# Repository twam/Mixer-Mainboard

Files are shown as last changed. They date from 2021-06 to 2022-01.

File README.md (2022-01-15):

Mixer-Mainboard
===

This repository is part of the USB audio mixer project described on https://www.twam.info/general/building-a-custom-usb-audio-mixer.

## License

[][cc-by-sa]

This work is licensed under a [Creative Commons Attribution-NonCommercial-ShareAlike 4.0 International License][cc-by-sa].

[][cc-by-sa]

[cc-by-sa]: http://creativecommons.org/licenses/by-nc-sa/4.0/
[cc-by-sa-image]: https://licensebuttons.net/l/by-nc-sa/4.0/88x31.png
[cc-by-sa-shield]: https://img.shields.io/badge/License-CC%20BY--NC--SA%204.0-lightgrey.svg

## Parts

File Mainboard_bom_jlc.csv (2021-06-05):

Comment | Designator | Footprint | LCSC Part #
6p8 | C7,C8,C9 | C_0402_1005Metric | C1576
22u | C12,C18 | C_0603_1608Metric | C59461
1u | C29,C34,C36,C38,C40,C42,C44,C46,C48,C21,C23,C31,C25,C27 | C_0402_1005Metric | C52923
10u | C101,C201,C19,C3 | C_0805_2012Metric | C15850
1u | C102,C202,C13,C14,C15 | C_0603_1608Metric | C15849
10u | C103,C203,C10,C11,C16,C17 | C_0603_1608Metric | C19702
2u2 | C104,C106,C204,C206 | C_0603_1608Metric | C23630
20pF | C501,C502 | C_0402_1005Metric | C1554
4u7 | C503,C505,C515,C4,C5,C6 | C_0603_1608Metric | C19666
100n | C504,C506,C507,C508,C509,C510,C511,C512,C513,C514,C516,C105,C107,C205,C207,C1,C2,C33,C35,C37,C39,C41,C43,C45,C47,C49,C20,C22,C24,C30,C32,C50,C26,C28,C51,C52,C53 | C_0402_1005Metric | C1525
yellow | D4 | LED_0603_1608Metric | C72038
white | D5 | LED_0603_1608Metric | C2290
blue | D6 | LED_0603_1608Metric | C72041
green | D7,D1,D2,D3 | LED_0603_1608Metric | C72043
red | D8,D9,D10,D12,D11 | LED_0603_1608Metric | C2286
2A | F1,F2 | Fuse_0603_1608Metric_Pad1.05x0.95mm_HandSolder | C187605
USB1 | J501,J101,J201 | USB_C_Receptacle_XKB_TYPE-C-31-M-12 | C165948
600R/100M | L1,L501,L101,L201,L6,L2 | L_0805_2012Metric | C1017
2u2 | L3,L4,L5 | L_0805_2012Metric | C216156
2N7002 | Q1 | SOT-23 | C8545
15k | R1,R9 | R_0402_1005Metric | C25756
1k | R7,R14,R18 | R_0402_1005Metric | C11702
68k | R8 | R_0402_1005Metric | C36871
150k | R10 | R_0402_1005Metric | C25755
47k | R11 | R_0402_1005Metric | C25792
100k | R12,R13 | R_0402_1005Metric | C25741
51R | R24 | R_0402_1005Metric | C25125
1k5 | R39 | R_0402_1005Metric | C25867
8k06 1% | R105,R205 | R_0603_1608Metric | C23112
5k1 | R501,R502,R101,R102,R201,R202 | R_0402_1005Metric | C25905
12k | R503 | R_0402_1005Metric | C25752
10k | R504,R505,R506,R507,R104,R204,R21,R25,R26,R27,R28,R30,R31,R32,R3,R4,R5 | R_0402_1005Metric | C25744
2k2 | R508 | R_0402_1005Metric | C25879
4k7 | R601,R602,R611,R612,R621,R622,R16,R20,R22,R23,R29,R33,R34,R35,R36,R37,R38,R2,R43,R19,R40,R41,R42 | R_0402_1005Metric | C25900
RESET | SW1 | SW_SPST_B3U-1000P | C231329
PROGRAM | SW2 | SW_SPST_B3U-1000P | C231329
BTN1 | SW3 | SW_SPST_B3U-1000P | C231329
BTN2 | SW4 | SW_SPST_B3U-1000P | C231329
BTN3 | SW5 | SW_SPST_B3U-1000P | C231329
W25Q128JVS | U2 | SOIC-8_5.23x5.23mm_P1.27mm | C97521
TLV62569DBV | U3,U4,U5 | SOT-23-5 | C141836
CAT24C256 | U6 | SOIC-8_3.9x4.9mm_P1.27mm | C6482
USB3320 | U101,U201 | QFN-32-1EP_5x5mm_P0.5mm_EP3.3x3.3mm | C132156
TPS76318 | U102,U202 | SOT-23-5 | C7099
FT2232HQ | U501 | QFN-64-1EP_9x9mm_P0.5mm_EP4.35x4.35mm | C193662
93LCxxBxxOT | U502 | SOT-23-6 | C190271
SG-5032CAN | X1 | Oscillator_SMD_SeikoEpson_SG8002LB-4Pin_5.0x3.2mm | C37076
12M | Y501 | Crystal_SMD_3225-4Pin_3.2x2.5mm | C9002

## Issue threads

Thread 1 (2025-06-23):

Gateware

DragonHunter274, 2025-06-23:
I want to build a similar mixer, would you mind sharing the gateware you use?
i am especially interested in the usb part

twam, 2025-06-23:
Hey!
Although the mixer is running fine for me, the gateware is currently not in a buildable state due to the many changes in nmigen/Amaranth in the last months/years. Therefore I'm a little hesitant to put it online.

The USB part is mainly based on https://github.com/greatscottgadgets/luna. If you have experience with that or maybe have it already running I can dig out the USB descriptors and the USB device I used.

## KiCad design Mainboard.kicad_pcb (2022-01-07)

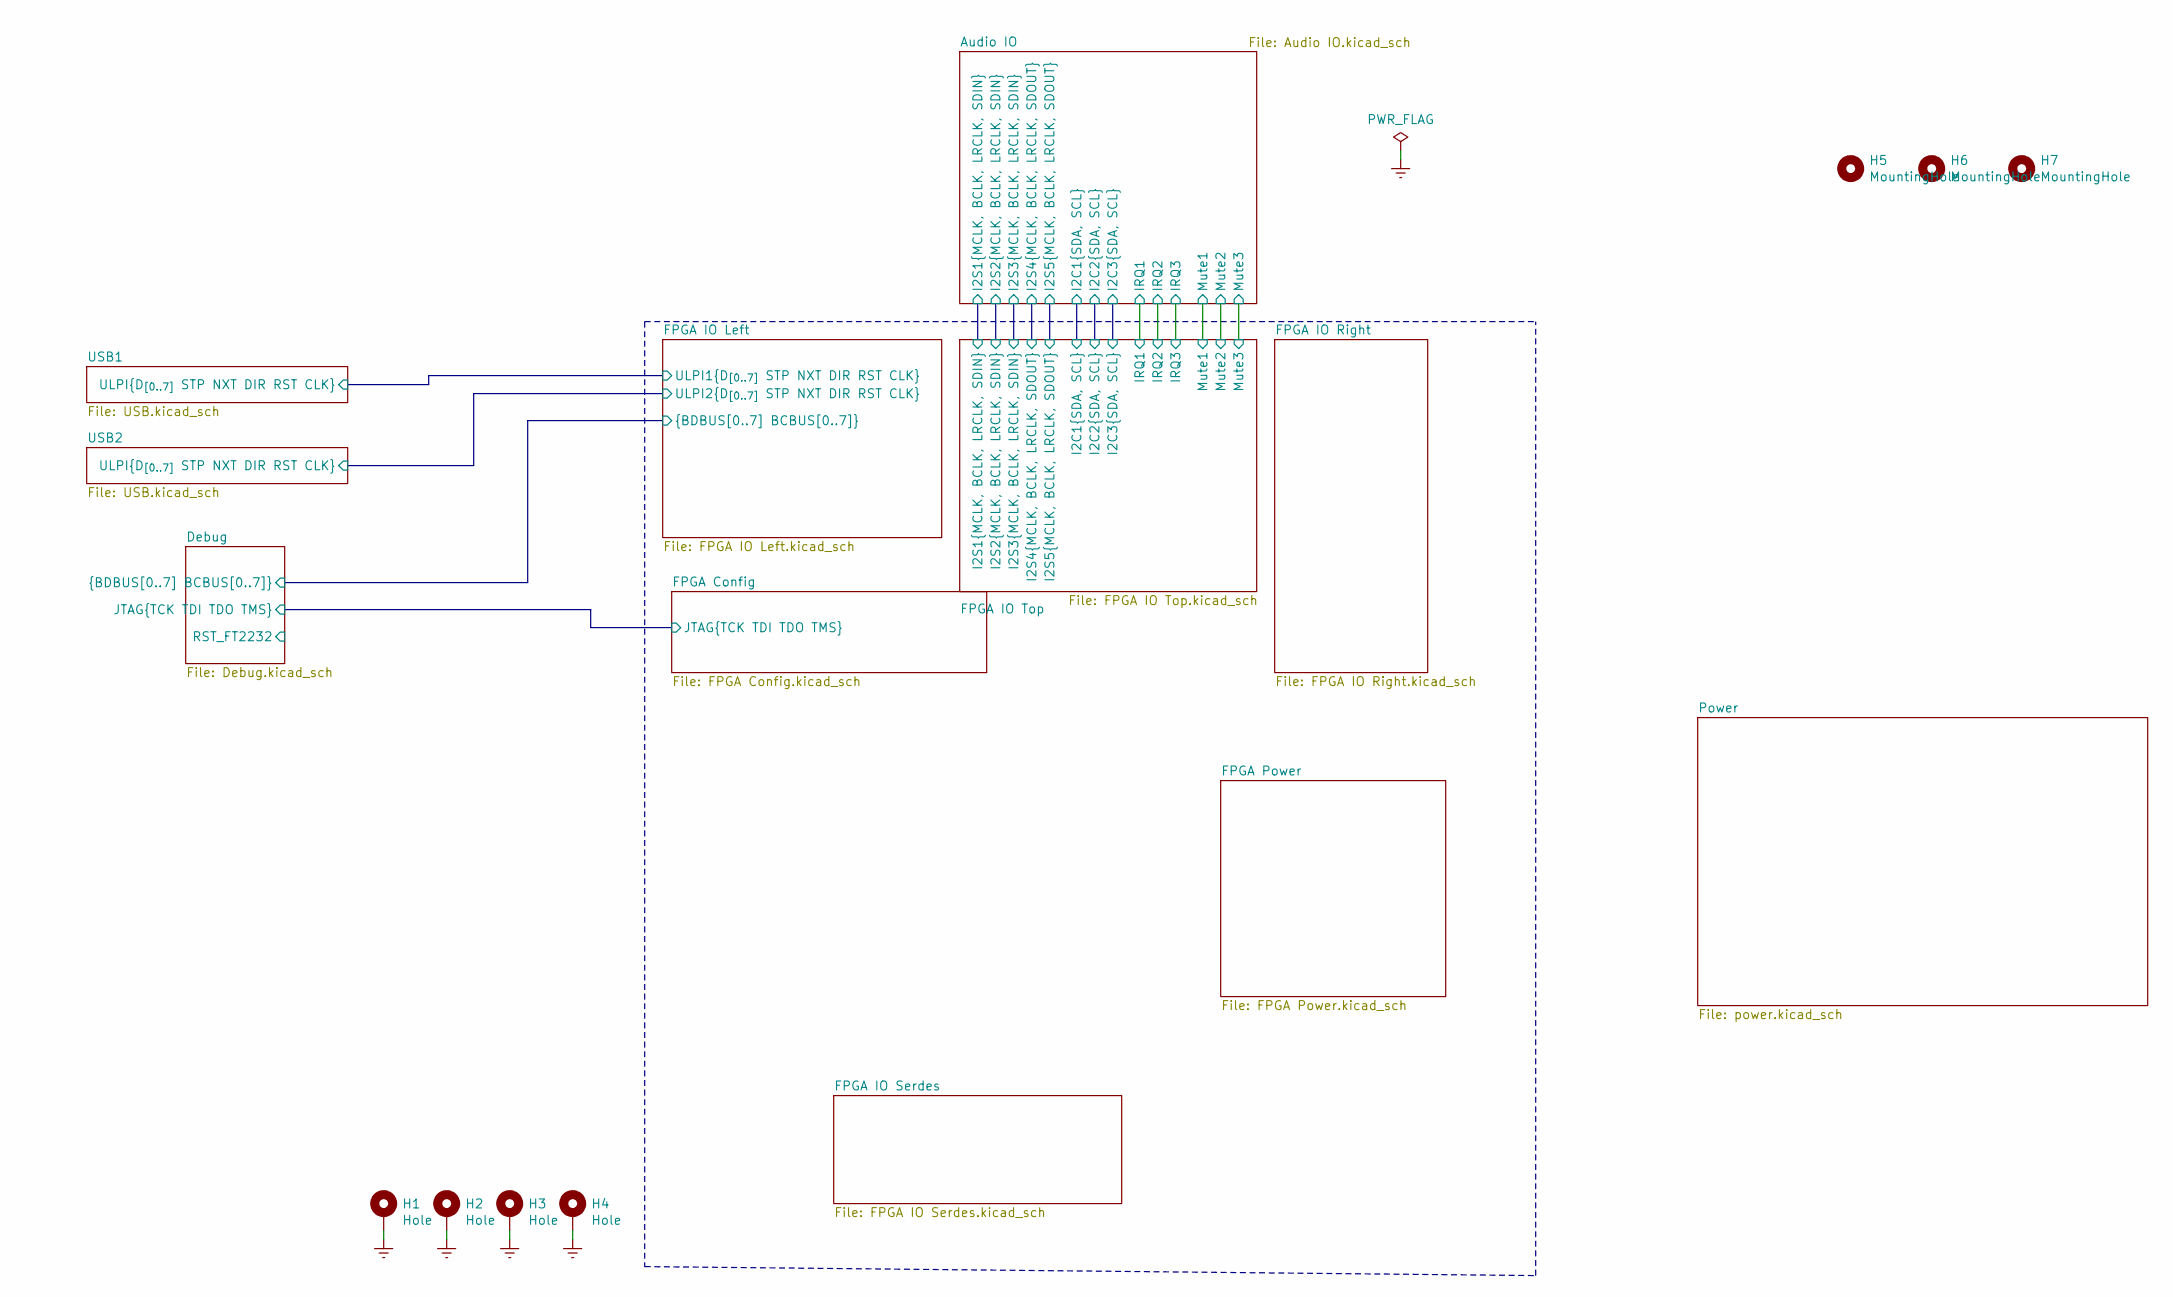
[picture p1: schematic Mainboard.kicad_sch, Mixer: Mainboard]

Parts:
H1, H2, H3, H4: Hole; MountingHole_3.2mm_M3_DIN965_Pad
H5, H6, H7: MountingHole; MountingHole_JLCPCB

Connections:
Earth: H1.1, H2.1, H3.1, H4.1; also elsewhere on the board

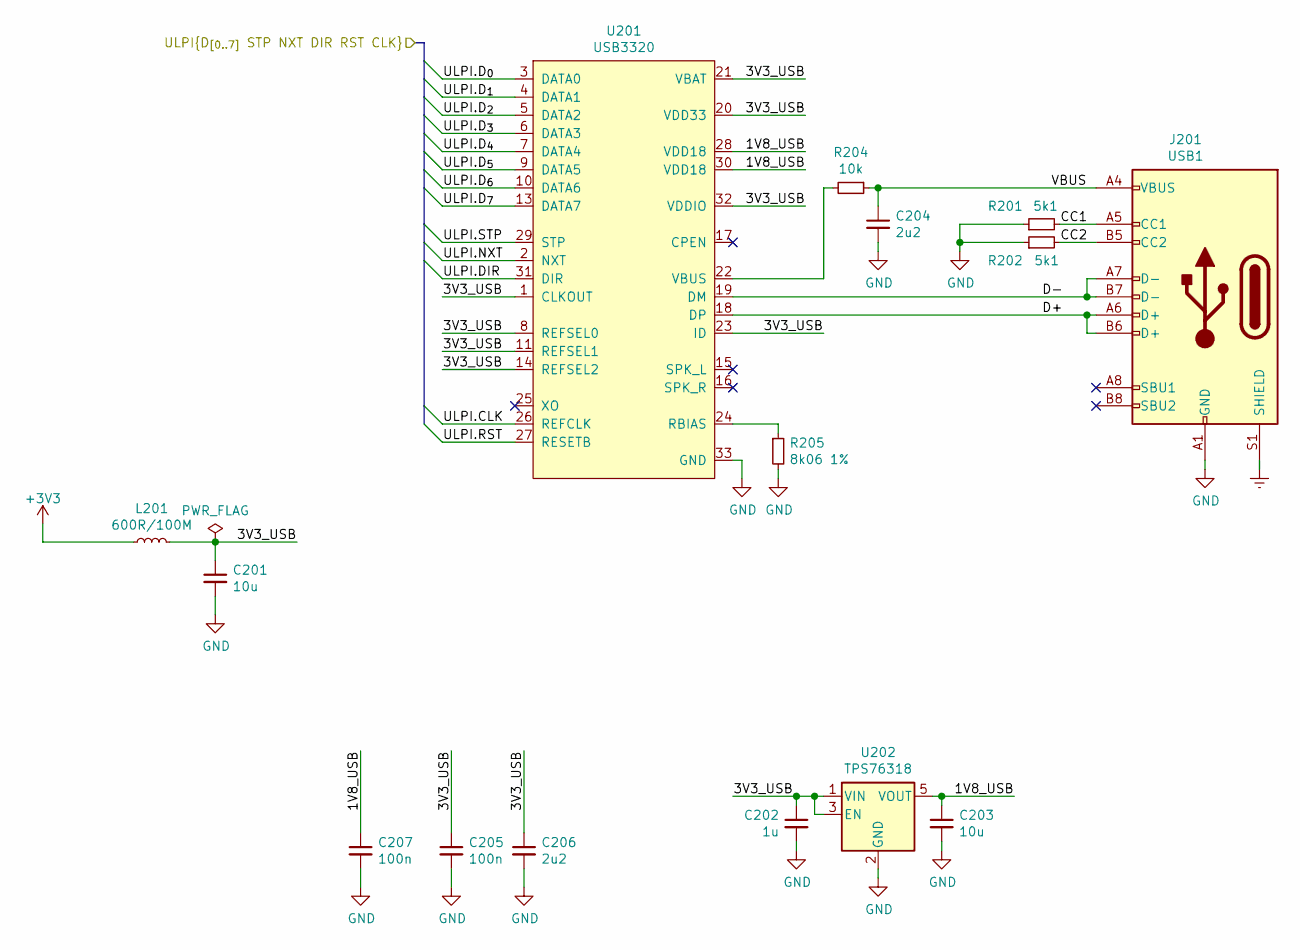
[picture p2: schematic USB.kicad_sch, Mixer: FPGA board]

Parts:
C201: 10u; C_0805_2012Metric; LCSC C15850
C202: 1u; C_0603_1608Metric; LCSC C15849
C203: 10u; C_0603_1608Metric; LCSC C19702
C204, C206: 2u2; C_0603_1608Metric; LCSC C23630
C205, C207: 100n; C_0402_1005Metric; LCSC C1525
J201: USB1; USB_C_Receptacle_XKB_TYPE-C-31-M-12; LCSC C165948
L201: 600R/100M; L_0805_2012Metric; LCSC C1017
R201, R202: 5k1; R_0402_1005Metric; LCSC C25905
R204: 10k; R_0402_1005Metric; LCSC C25744
R205: 8k06 1%; R_0603_1608Metric; LCSC C23112
U201: USB3320; QFN-32-1EP_5x5mm_P0.5mm_EP3.3x3.3mm; LCSC C132156
U202: TPS76318; SOT-23-5; LCSC C7099

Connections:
+3V3: L201.1; also elsewhere on the board
/FPGA IO Left/ULPI2.CLK: U201.26 (REFCLK); also elsewhere on the board
/FPGA IO Left/ULPI2.DIR: U201.31 (DIR); also elsewhere on the board
/FPGA IO Left/ULPI2.D_{0}: U201.3 (DATA0); also elsewhere on the board
/FPGA IO Left/ULPI2.D_{1}: U201.4 (DATA1); also elsewhere on the board
/FPGA IO Left/ULPI2.D_{2}: U201.5 (DATA2); also elsewhere on the board
/FPGA IO Left/ULPI2.D_{3}: U201.6 (DATA3); also elsewhere on the board
/FPGA IO Left/ULPI2.D_{4}: U201.7 (DATA4); also elsewhere on the board
/FPGA IO Left/ULPI2.D_{5}: U201.9 (DATA5); also elsewhere on the board
/FPGA IO Left/ULPI2.D_{6}: U201.10 (DATA6); also elsewhere on the board
/FPGA IO Left/ULPI2.D_{7}: U201.13 (DATA7); also elsewhere on the board
/FPGA IO Left/ULPI2.NXT: U201.2 (NXT); also elsewhere on the board
/FPGA IO Left/ULPI2.RST: U201.27 (RESETB); also elsewhere on the board
/FPGA IO Left/ULPI2.STP: U201.29 (STP); also elsewhere on the board
/USB2/1V8_USB: C203.1, C207.1, U201.28 (VDD18), U201.30 (VDD18), U202.5 (VOUT)
/USB2/3V3_USB: C201.1, C202.1, C205.1, C206.1, L201.2, U201.1 (CLKOUT), U201.8 (REFSEL0), U201.11 (REFSEL1), U201.14 (REFSEL2), U201.20 (VDD33), U201.21 (VBAT), U201.23 (ID), U201.32 (VDDIO), U202.1 (VIN), U202.3 (EN)
/USB2/CC1: J201.A5 (CC1), R201.2
/USB2/CC2: J201.B5 (CC2), R202.2
/USB2/D+: J201.A6 (D+), J201.B6 (D+), U201.18 (DP)
/USB2/D-: J201.A7 (D-), J201.B7 (D-), U201.19 (DM)
/USB2/VBUS: C204.1, J201.A4 (VBUS), J201.A9 (VBUS), J201.B4 (VBUS), J201.B9 (VBUS), R204.1
Earth: J201.S1 (SHIELD); also elsewhere on the board
GND: C201.2, C202.2, C203.2, C204.2, C205.2, C206.2, C207.2, J201.A1 (GND), J201.A12 (GND), J201.B1 (GND), J201.B12 (GND), R201.1, R202.1, R205.2, U201.33 (GND), U202.2 (GND); also elsewhere on the board
unnamed: R204.2, U201.22 (VBUS)
unnamed: R205.1, U201.24 (RBIAS)

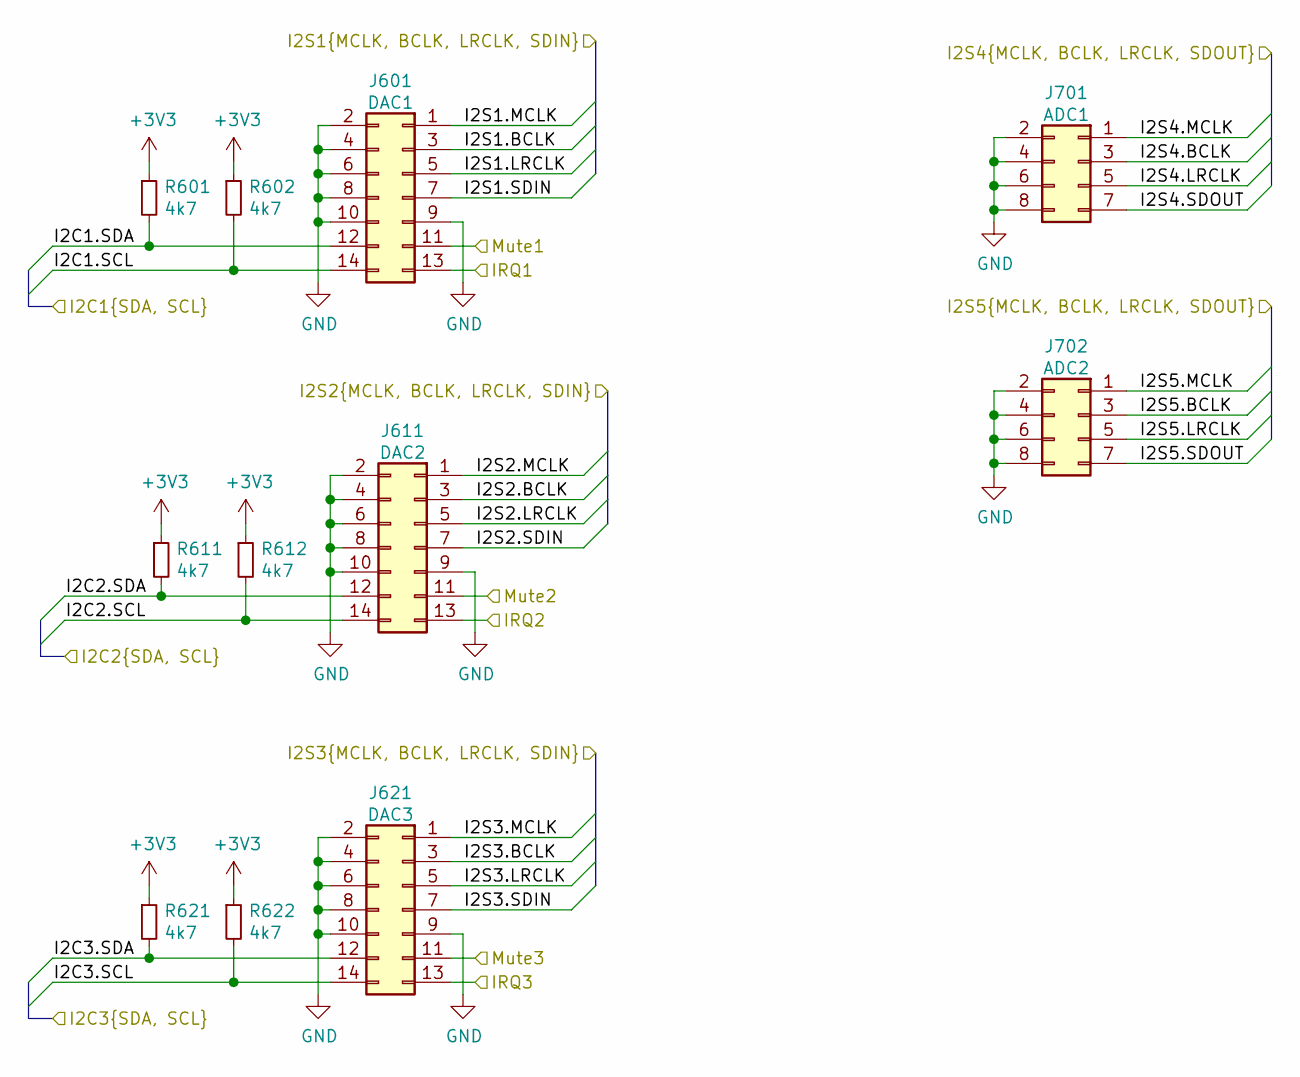
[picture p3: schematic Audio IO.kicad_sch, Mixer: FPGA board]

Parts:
J601: DAC1; PinHeader_2x07_P2.54mm_Vertical
J611: DAC2; PinHeader_2x07_P2.54mm_Vertical
J621: DAC3; PinHeader_2x07_P2.54mm_Vertical
J701: ADC1; PinHeader_2x04_P2.54mm_Vertical
J702: ADC2; PinHeader_2x04_P2.54mm_Vertical
R601, R602, R611, R612, R621, R622: 4k7; R_0402_1005Metric; LCSC C25900

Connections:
+3V3: R601.1, R602.1, R611.1, R612.1, R621.1, R622.1; also elsewhere on the board
/Audio IO/I2C1.SCL: J601.14, R602.2; also elsewhere on the board
/Audio IO/I2C1.SDA: J601.12, R601.2; also elsewhere on the board
/Audio IO/I2C2.SCL: J611.14, R612.2; also elsewhere on the board
/Audio IO/I2C2.SDA: J611.12, R611.2; also elsewhere on the board
/Audio IO/I2C3.SCL: J621.14, R622.2; also elsewhere on the board
/Audio IO/I2C3.SDA: J621.12, R621.2; also elsewhere on the board
/Audio IO/I2S1.BCLK: J601.3; also elsewhere on the board
/Audio IO/I2S1.LRCLK: J601.5; also elsewhere on the board
/Audio IO/I2S1.MCLK: J601.1; also elsewhere on the board
/Audio IO/I2S1.SDIN: J601.7; also elsewhere on the board
/Audio IO/I2S2.BCLK: J611.3; also elsewhere on the board
/Audio IO/I2S2.LRCLK: J611.5; also elsewhere on the board
/Audio IO/I2S2.MCLK: J611.1; also elsewhere on the board
/Audio IO/I2S2.SDIN: J611.7; also elsewhere on the board
/Audio IO/I2S3.BCLK: J621.3; also elsewhere on the board
/Audio IO/I2S3.LRCLK: J621.5; also elsewhere on the board
/Audio IO/I2S3.MCLK: J621.1; also elsewhere on the board
/Audio IO/I2S3.SDIN: J621.7; also elsewhere on the board
/Audio IO/I2S4.BCLK: J701.3; also elsewhere on the board
/Audio IO/I2S4.LRCLK: J701.5; also elsewhere on the board
/Audio IO/I2S4.MCLK: J701.1; also elsewhere on the board
/Audio IO/I2S4.SDOUT: J701.7; also elsewhere on the board
/Audio IO/I2S5.BCLK: J702.3; also elsewhere on the board
/Audio IO/I2S5.LRCLK: J702.5; also elsewhere on the board
/Audio IO/I2S5.MCLK: J702.1; also elsewhere on the board
/Audio IO/I2S5.SDOUT: J702.7; also elsewhere on the board
/Audio IO/IRQ1: J601.13; also elsewhere on the board
/Audio IO/IRQ2: J611.13; also elsewhere on the board
/Audio IO/IRQ3: J621.13; also elsewhere on the board
/Audio IO/Mute1: J601.11; also elsewhere on the board
/Audio IO/Mute2: J611.11; also elsewhere on the board
/Audio IO/Mute3: J621.11; also elsewhere on the board
GND: J601.2, J601.4, J601.6, J601.8, J601.9, J601.10, J611.2, J611.4, J611.6, J611.8, J611.9, J611.10, J621.2, J621.4, J621.6, J621.8, J621.9, J621.10, J701.2, J701.4, J701.6, J701.8, J702.2, J702.4, J702.6, J702.8; also elsewhere on the board

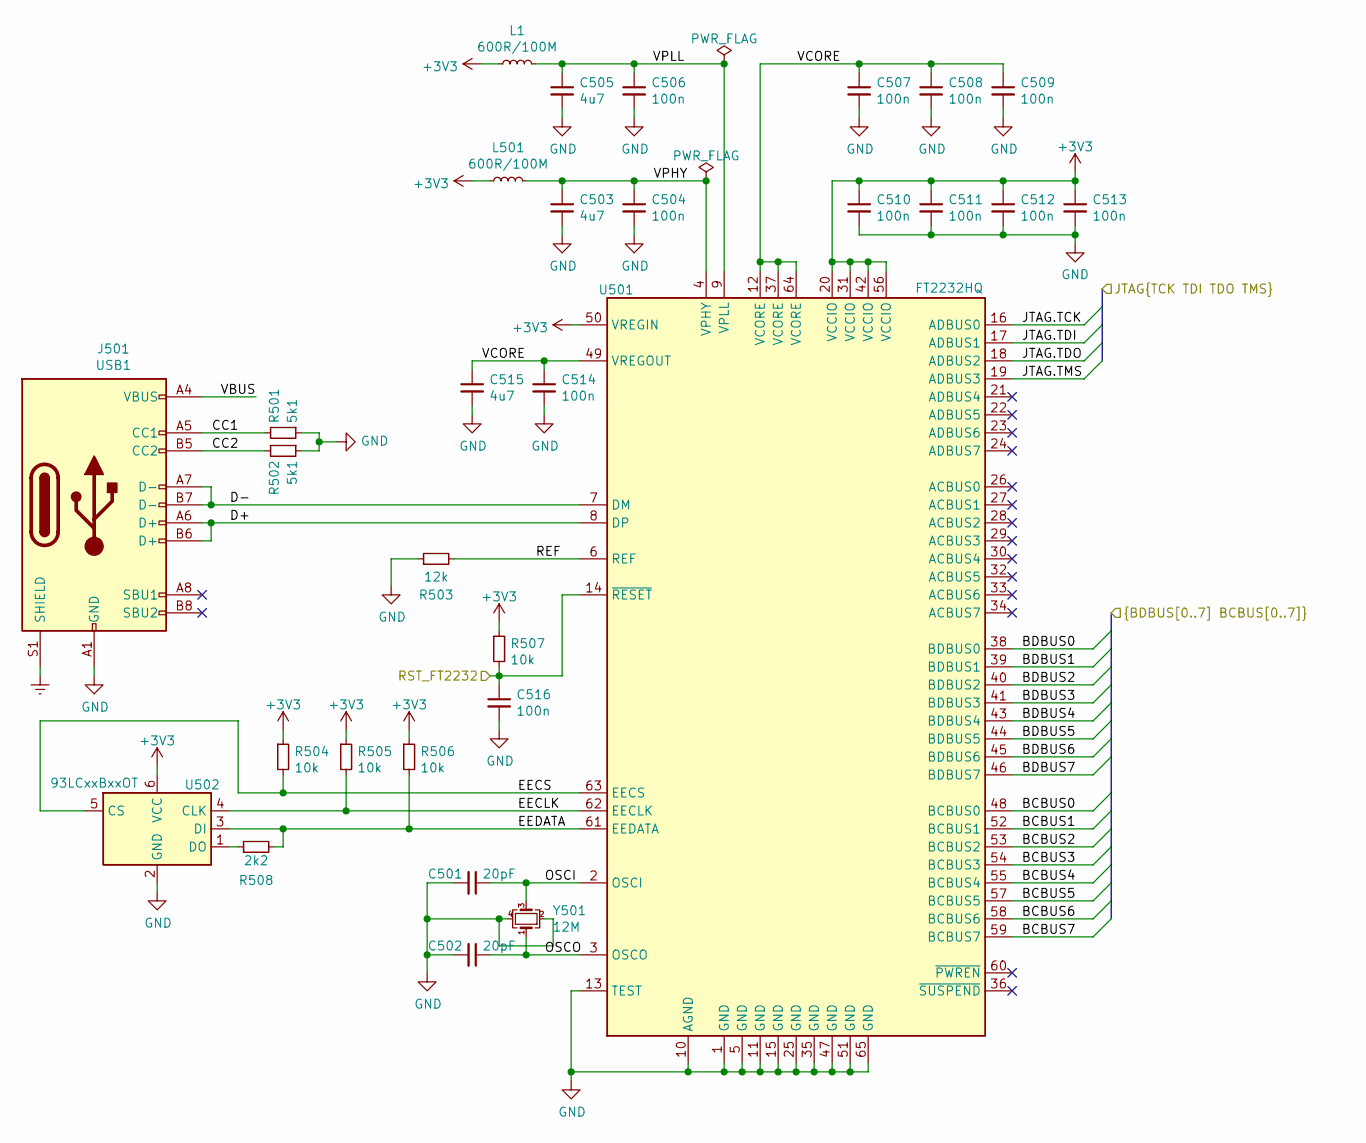
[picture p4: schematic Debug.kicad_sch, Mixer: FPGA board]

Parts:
C501, C502: 20pF; C_0402_1005Metric; LCSC C1554
C503, C505, C515: 4u7; C_0603_1608Metric; LCSC C19666
C504, C506, C507, C508, C509, C510, C511, C512, C513, C514, C516: 100n; C_0402_1005Metric; LCSC C1525
J501: USB1; USB_C_Receptacle_XKB_TYPE-C-31-M-12; LCSC C165948
L1, L501: 600R/100M; L_0805_2012Metric; LCSC C1017
R501, R502: 5k1; R_0402_1005Metric; LCSC C25905
R503: 12k; R_0402_1005Metric; LCSC C25752
R504, R505, R506, R507: 10k; R_0402_1005Metric; LCSC C25744
R508: 2k2; R_0402_1005Metric; LCSC C25879
U501: FT2232HQ; QFN-64-1EP_9x9mm_P0.5mm_EP4.35x4.35mm; LCSC C193662
U502: 93LCxxBxxOT; SOT-23-6; LCSC C190271
Y501: 12M; Crystal_SMD_3225-4Pin_3.2x2.5mm; LCSC C9002

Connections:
+3V3: C510.1, C511.1, C512.1, C513.1, L1.1, L501.1, R504.1, R505.1, R506.1, R507.2, U501.20 (VCCIO), U501.31 (VCCIO), U501.42 (VCCIO), U501.50 (VREGIN), U501.56 (VCCIO), U502.6 (VCC); also elsewhere on the board
/Debug/BCBUS0: U501.48 (BCBUS0); also elsewhere on the board
/Debug/BCBUS1: U501.52 (BCBUS1); also elsewhere on the board
/Debug/BCBUS2: U501.53 (BCBUS2); also elsewhere on the board
/Debug/BCBUS3: U501.54 (BCBUS3); also elsewhere on the board
/Debug/BCBUS4: U501.55 (BCBUS4); also elsewhere on the board
/Debug/BCBUS5: U501.57 (BCBUS5); also elsewhere on the board
/Debug/BCBUS6: U501.58 (BCBUS6); also elsewhere on the board
/Debug/BCBUS7: U501.59 (BCBUS7); also elsewhere on the board
/Debug/BDBUS0: U501.38 (BDBUS0); also elsewhere on the board
/Debug/BDBUS1: U501.39 (BDBUS1); also elsewhere on the board
/Debug/BDBUS2: U501.40 (BDBUS2); also elsewhere on the board
/Debug/BDBUS3: U501.41 (BDBUS3); also elsewhere on the board
/Debug/BDBUS4: U501.43 (BDBUS4); also elsewhere on the board
/Debug/BDBUS5: U501.44 (BDBUS5); also elsewhere on the board
/Debug/BDBUS6: U501.45 (BDBUS6); also elsewhere on the board
/Debug/BDBUS7: U501.46 (BDBUS7); also elsewhere on the board
/Debug/CC1: J501.A5 (CC1), R501.2
/Debug/CC2: J501.B5 (CC2), R502.2
/Debug/D+: J501.A6 (D+), J501.B6 (D+), U501.8 (DP)
/Debug/D-: J501.A7 (D-), J501.B7 (D-), U501.7 (DM)
/Debug/EECLK: R505.2, U501.62 (EECLK), U502.4 (CLK)
/Debug/EECS: R504.2, U501.63 (EECS), U502.5 (CS)
/Debug/EEDATA: R506.2, R508.2, U501.61 (EEDATA), U502.3 (DI)
/Debug/JTAG.TCK: U501.16 (ADBUS0); also elsewhere on the board
/Debug/JTAG.TDI: U501.17 (ADBUS1); also elsewhere on the board
/Debug/JTAG.TDO: U501.18 (ADBUS2); also elsewhere on the board
/Debug/JTAG.TMS: U501.19 (ADBUS3); also elsewhere on the board
/Debug/OSCI: C501.1, U501.2 (OSCI), Y501.3
/Debug/OSCO: C502.1, U501.3 (OSCO), Y501.1
/Debug/REF: R503.2, U501.6 (REF)
/Debug/RST_FT2232: C516.1, R507.1, U501.14 (~RESET)
/Debug/VBUS: J501.A4 (VBUS), J501.A9 (VBUS), J501.B4 (VBUS), J501.B9 (VBUS)
/Debug/VCORE: C507.1, C508.1, C509.1, C514.1, C515.1, U501.12 (VCORE), U501.37 (VCORE), U501.49 (VREGOUT), U501.64 (VCORE)
/Debug/VPHY: C503.1, C504.1, L501.2, U501.4 (VPHY)
/Debug/VPLL: C505.1, C506.1, L1.2, U501.9 (VPLL)
Earth: J501.S1 (SHIELD); also elsewhere on the board
GND: C501.2, C502.2, C503.2, C504.2, C505.2, C506.2, C507.2, C508.2, C509.2, C510.2, C511.2, C512.2, C513.2, C514.2, C515.2, C516.2, J501.A1 (GND), J501.A12 (GND), J501.B1 (GND), J501.B12 (GND), R501.1, R502.1, R503.1, U501.1 (GND), U501.5 (GND), U501.10 (AGND), U501.11 (GND), U501.13 (TEST), U501.15 (GND), U501.25 (GND), U501.35 (GND), U501.47 (GND), U501.51 (GND), U501.65 (GND), U502.2 (GND), Y501.2, Y501.4; also elsewhere on the board
unnamed: R508.1, U502.1 (DO)

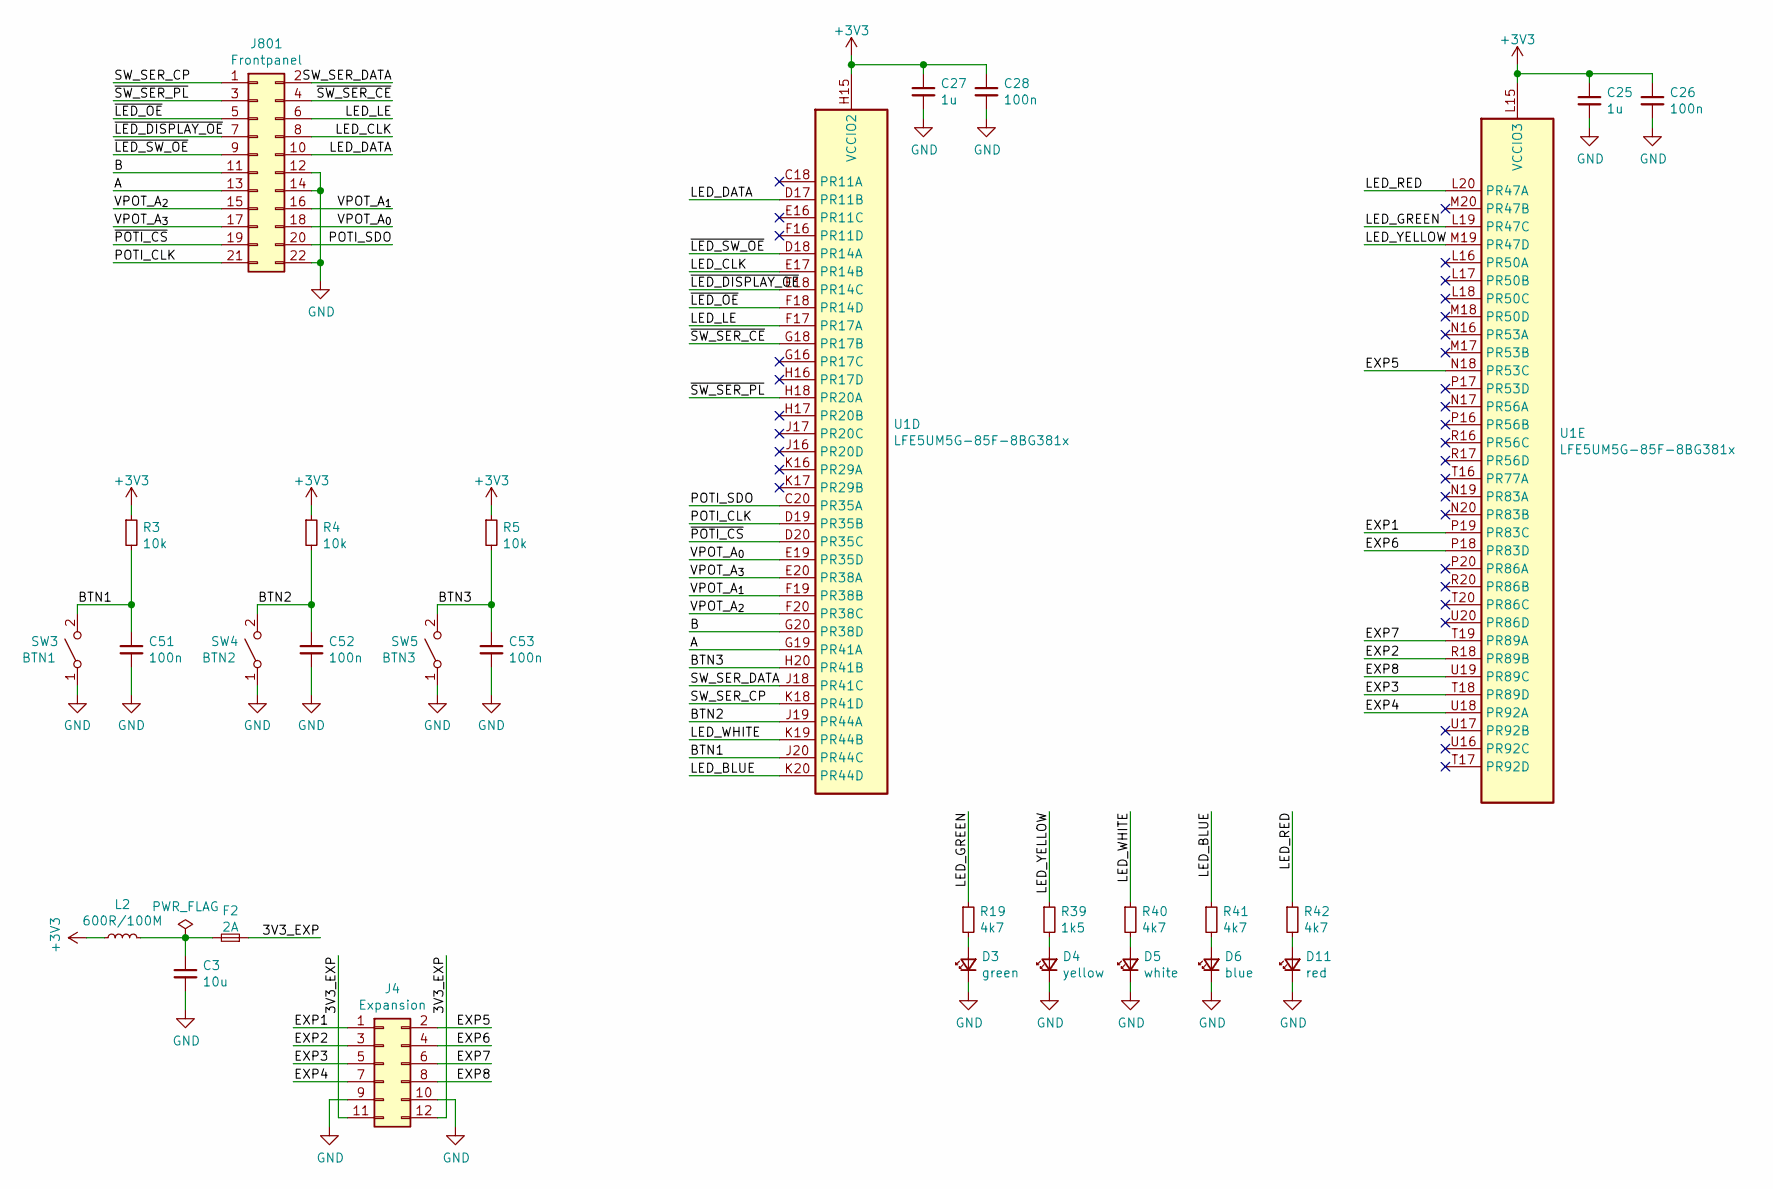
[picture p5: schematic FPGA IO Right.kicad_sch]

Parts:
C3: 10u; C_0805_2012Metric; LCSC C15850
C25, C27: 1u; C_0402_1005Metric; LCSC C52923
C26, C28, C51, C52, C53: 100n; C_0402_1005Metric; LCSC C1525
D3: green; LED_0603_1608Metric; LCSC C72043
D4: yellow; LED_0603_1608Metric; LCSC C72038
D5: white; LED_0603_1608Metric; LCSC C2290
D6: blue; LED_0603_1608Metric; LCSC C72041
D11: red; LED_0603_1608Metric; LCSC C2286
F2: 2A; Fuse_0603_1608Metric_Pad1.05x0.95mm_HandSolder; LCSC C187605
J4: Expansion; PinHeader_2x06_P2.54mm_Vertical
J801: Frontpanel; PinHeader_2x11_P2.54mm_Vertical
L2: 600R/100M; L_0805_2012Metric; LCSC C1017
R3, R4, R5: 10k; R_0402_1005Metric; LCSC C25744
R19, R40, R41, R42: 4k7; R_0402_1005Metric; LCSC C25900
R39: 1k5; R_0402_1005Metric; LCSC C25867
SW3: BTN1; SW_SPST_B3U-1000P; LCSC C231329
SW4: BTN2; SW_SPST_B3U-1000P; LCSC C231329
SW5: BTN3; SW_SPST_B3U-1000P; LCSC C231329
U1: LFE5UM5G-85F-8BG381x; Lattice_caBGA-381_17.0x17.0mm_Layout20x20_P0.8mm_Ball0.4mm_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

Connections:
+3V3: C25.1, C26.1, C27.1, C28.1, L2.1, R3.1, R4.1, R5.1, U1.H14 (VCCIO2), U1.H15 (VCCIO2), U1.J15 (VCCIO2), U1.L14 (VCCIO3), U1.L15 (VCCIO3), U1.M15 (VCCIO3); also elsewhere on the board
/FPGA IO Right/3V3_EXP: F2.1, J4.11, J4.12
/FPGA IO Right/A: J801.13, U1.G19 (PR41A)
/FPGA IO Right/B: J801.11, U1.G20 (PR38D)
/FPGA IO Right/BTN1: C51.1, R3.2, SW3.2 (B), U1.J20 (PR44C)
/FPGA IO Right/BTN2: C52.1, R4.2, SW4.2 (B), U1.J19 (PR44A)
/FPGA IO Right/BTN3: C53.1, R5.2, SW5.2 (B), U1.H20 (PR41B)
/FPGA IO Right/EXP1: J4.1, U1.P19 (PR83C)
/FPGA IO Right/EXP2: J4.3, U1.R18 (PR89B)
/FPGA IO Right/EXP3: J4.5, U1.T18 (PR89D)
/FPGA IO Right/EXP4: J4.7, U1.U18 (PR92A)
/FPGA IO Right/EXP5: J4.2, U1.N18 (PR53C)
/FPGA IO Right/EXP6: J4.4, U1.P18 (PR83D)
/FPGA IO Right/EXP7: J4.6, U1.T19 (PR89A)
/FPGA IO Right/EXP8: J4.8, U1.U19 (PR89C)
/FPGA IO Right/LED_BLUE: R41.1, U1.K20 (PR44D)
/FPGA IO Right/LED_CLK: J801.8, U1.E17 (PR14B)
/FPGA IO Right/LED_DATA: J801.10, U1.D17 (PR11B)
/FPGA IO Right/LED_GREEN: R19.1, U1.L19 (PR47C)
/FPGA IO Right/LED_LE: J801.6, U1.F17 (PR17A)
/FPGA IO Right/LED_RED: R42.1, U1.L20 (PR47A)
/FPGA IO Right/LED_WHITE: R40.1, U1.K19 (PR44B)
/FPGA IO Right/LED_YELLOW: R39.1, U1.M19 (PR47D)
/FPGA IO Right/POTI_CLK: J801.21, U1.D19 (PR35B)
/FPGA IO Right/POTI_SDO: J801.20, U1.C20 (PR35A)
/FPGA IO Right/SW_SER_CP: J801.1, U1.K18 (PR41D)
/FPGA IO Right/SW_SER_DATA: J801.2, U1.J18 (PR41C)
/FPGA IO Right/VPOT_A_{0}: J801.18, U1.E19 (PR35D)
/FPGA IO Right/VPOT_A_{1}: J801.16, U1.F19 (PR38B)
/FPGA IO Right/VPOT_A_{2}: J801.15, U1.F20 (PR38C)
/FPGA IO Right/VPOT_A_{3}: J801.17, U1.E20 (PR38A)
/FPGA IO Right/~LED_DISPLAY_OE: J801.7, U1.E18 (PR14C)
/FPGA IO Right/~LED_OE: J801.5, U1.F18 (PR14D)
/FPGA IO Right/~LED_SW_OE: J801.9, U1.D18 (PR14A)
/FPGA IO Right/~POTI_CS: J801.19, U1.D20 (PR35C)
/FPGA IO Right/~SW_SER_CE: J801.4, U1.G18 (PR17B)
/FPGA IO Right/~SW_SER_PL: J801.3, U1.H18 (PR20A)
GND: C3.2, C25.2, C26.2, C27.2, C28.2, C51.2, C52.2, C53.2, D3.1 (K), D4.1 (K), D5.1 (K), D6.1 (K), D11.1 (K), J4.9, J4.10, J801.12, J801.14, J801.22, SW3.1 (A), SW4.1 (A), SW5.1 (A); also elsewhere on the board
unnamed: C3.1, F2.2, L2.2
unnamed: D3.2 (A), R19.2
unnamed: D4.2 (A), R39.2
unnamed: D5.2 (A), R40.2
unnamed: D6.2 (A), R41.2
unnamed: D11.2 (A), R42.2

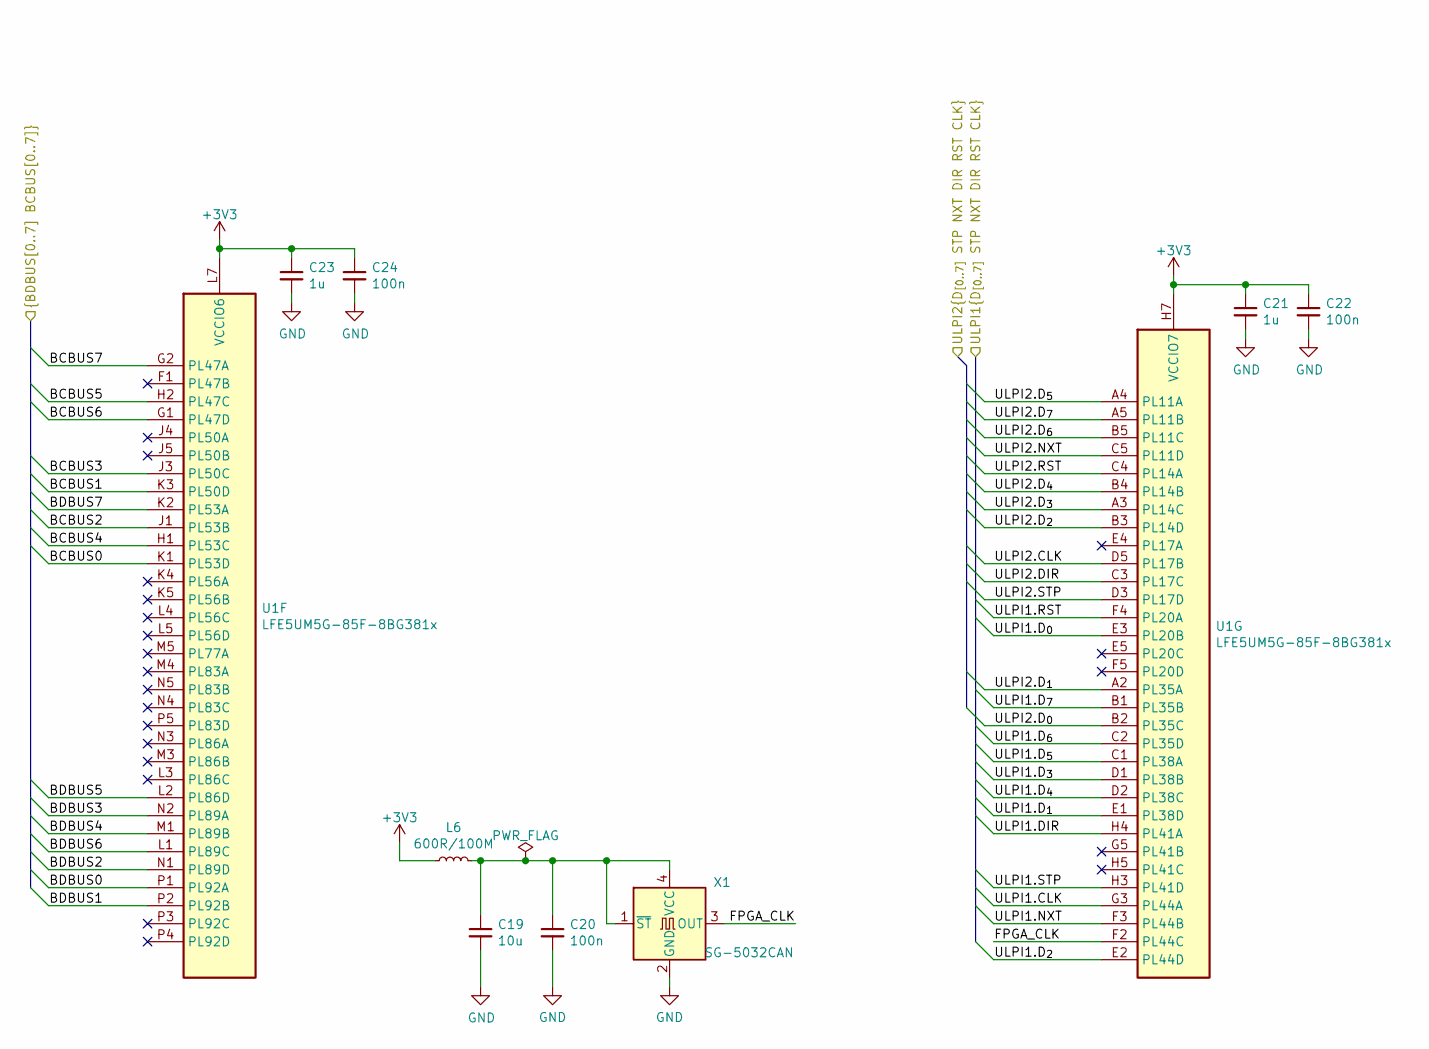
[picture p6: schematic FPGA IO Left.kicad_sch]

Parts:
C19: 10u; C_0805_2012Metric; LCSC C15850
C20, C22, C24: 100n; C_0402_1005Metric; LCSC C1525
C21, C23: 1u; C_0402_1005Metric; LCSC C52923
L6: 600R/100M; L_0805_2012Metric; LCSC C1017
U1: LFE5UM5G-85F-8BG381x; Lattice_caBGA-381_17.0x17.0mm_Layout20x20_P0.8mm_Ball0.4mm_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
X1: SG-5032CAN; Oscillator_SMD_SeikoEpson_SG8002LB-4Pin_5.0x3.2mm; LCSC C37076

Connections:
+3V3: C21.1, C22.1, C23.1, C24.1, L6.1, U1.H6 (VCCIO7), U1.H7 (VCCIO7), U1.J6 (VCCIO7), U1.L6 (VCCIO6), U1.L7 (VCCIO6), U1.M6 (VCCIO6); also elsewhere on the board
/Debug/BCBUS0: U1.K1 (PL53D); also elsewhere on the board
/Debug/BCBUS1: U1.K3 (PL50D); also elsewhere on the board
/Debug/BCBUS2: U1.J1 (PL53B); also elsewhere on the board
/Debug/BCBUS3: U1.J3 (PL50C); also elsewhere on the board
/Debug/BCBUS4: U1.H1 (PL53C); also elsewhere on the board
/Debug/BCBUS5: U1.H2 (PL47C); also elsewhere on the board
/Debug/BCBUS6: U1.G1 (PL47D); also elsewhere on the board
/Debug/BCBUS7: U1.G2 (PL47A); also elsewhere on the board
/Debug/BDBUS0: U1.P1 (PL92A); also elsewhere on the board
/Debug/BDBUS1: U1.P2 (PL92B); also elsewhere on the board
/Debug/BDBUS2: U1.N1 (PL89D); also elsewhere on the board
/Debug/BDBUS3: U1.N2 (PL89A); also elsewhere on the board
/Debug/BDBUS4: U1.M1 (PL89B); also elsewhere on the board
/Debug/BDBUS5: U1.L2 (PL86D); also elsewhere on the board
/Debug/BDBUS6: U1.L1 (PL89C); also elsewhere on the board
/Debug/BDBUS7: U1.K2 (PL53A); also elsewhere on the board
/FPGA IO Left/FPGA_CLK: U1.F2 (PL44C), X1.3 (OUT)
/FPGA IO Left/ULPI1.CLK: U1.G3 (PL44A); also elsewhere on the board
/FPGA IO Left/ULPI1.DIR: U1.H4 (PL41A); also elsewhere on the board
/FPGA IO Left/ULPI1.D_{0}: U1.E3 (PL20B); also elsewhere on the board
/FPGA IO Left/ULPI1.D_{1}: U1.E1 (PL38D); also elsewhere on the board
/FPGA IO Left/ULPI1.D_{2}: U1.E2 (PL44D); also elsewhere on the board
/FPGA IO Left/ULPI1.D_{3}: U1.D1 (PL38B); also elsewhere on the board
/FPGA IO Left/ULPI1.D_{4}: U1.D2 (PL38C); also elsewhere on the board
/FPGA IO Left/ULPI1.D_{5}: U1.C1 (PL38A); also elsewhere on the board
/FPGA IO Left/ULPI1.D_{6}: U1.C2 (PL35D); also elsewhere on the board
/FPGA IO Left/ULPI1.D_{7}: U1.B1 (PL35B); also elsewhere on the board
/FPGA IO Left/ULPI1.NXT: U1.F3 (PL44B); also elsewhere on the board
/FPGA IO Left/ULPI1.RST: U1.F4 (PL20A); also elsewhere on the board
/FPGA IO Left/ULPI1.STP: U1.H3 (PL41D); also elsewhere on the board
/FPGA IO Left/ULPI2.CLK: U1.D5 (PL17B); also elsewhere on the board
/FPGA IO Left/ULPI2.DIR: U1.C3 (PL17C); also elsewhere on the board
/FPGA IO Left/ULPI2.D_{0}: U1.B2 (PL35C); also elsewhere on the board
/FPGA IO Left/ULPI2.D_{1}: U1.A2 (PL35A); also elsewhere on the board
/FPGA IO Left/ULPI2.D_{2}: U1.B3 (PL14D); also elsewhere on the board
/FPGA IO Left/ULPI2.D_{3}: U1.A3 (PL14C); also elsewhere on the board
/FPGA IO Left/ULPI2.D_{4}: U1.B4 (PL14B); also elsewhere on the board
/FPGA IO Left/ULPI2.D_{5}: U1.A4 (PL11A); also elsewhere on the board
/FPGA IO Left/ULPI2.D_{6}: U1.B5 (PL11C); also elsewhere on the board
/FPGA IO Left/ULPI2.D_{7}: U1.A5 (PL11B); also elsewhere on the board
/FPGA IO Left/ULPI2.NXT: U1.C5 (PL11D); also elsewhere on the board
/FPGA IO Left/ULPI2.RST: U1.C4 (PL14A); also elsewhere on the board
/FPGA IO Left/ULPI2.STP: U1.D3 (PL17D); also elsewhere on the board
GND: C19.2, C20.2, C21.2, C22.2, C23.2, C24.2, X1.2 (GND); also elsewhere on the board
unnamed: C19.1, C20.1, L6.2, X1.1 (~ST), X1.4 (VCC)

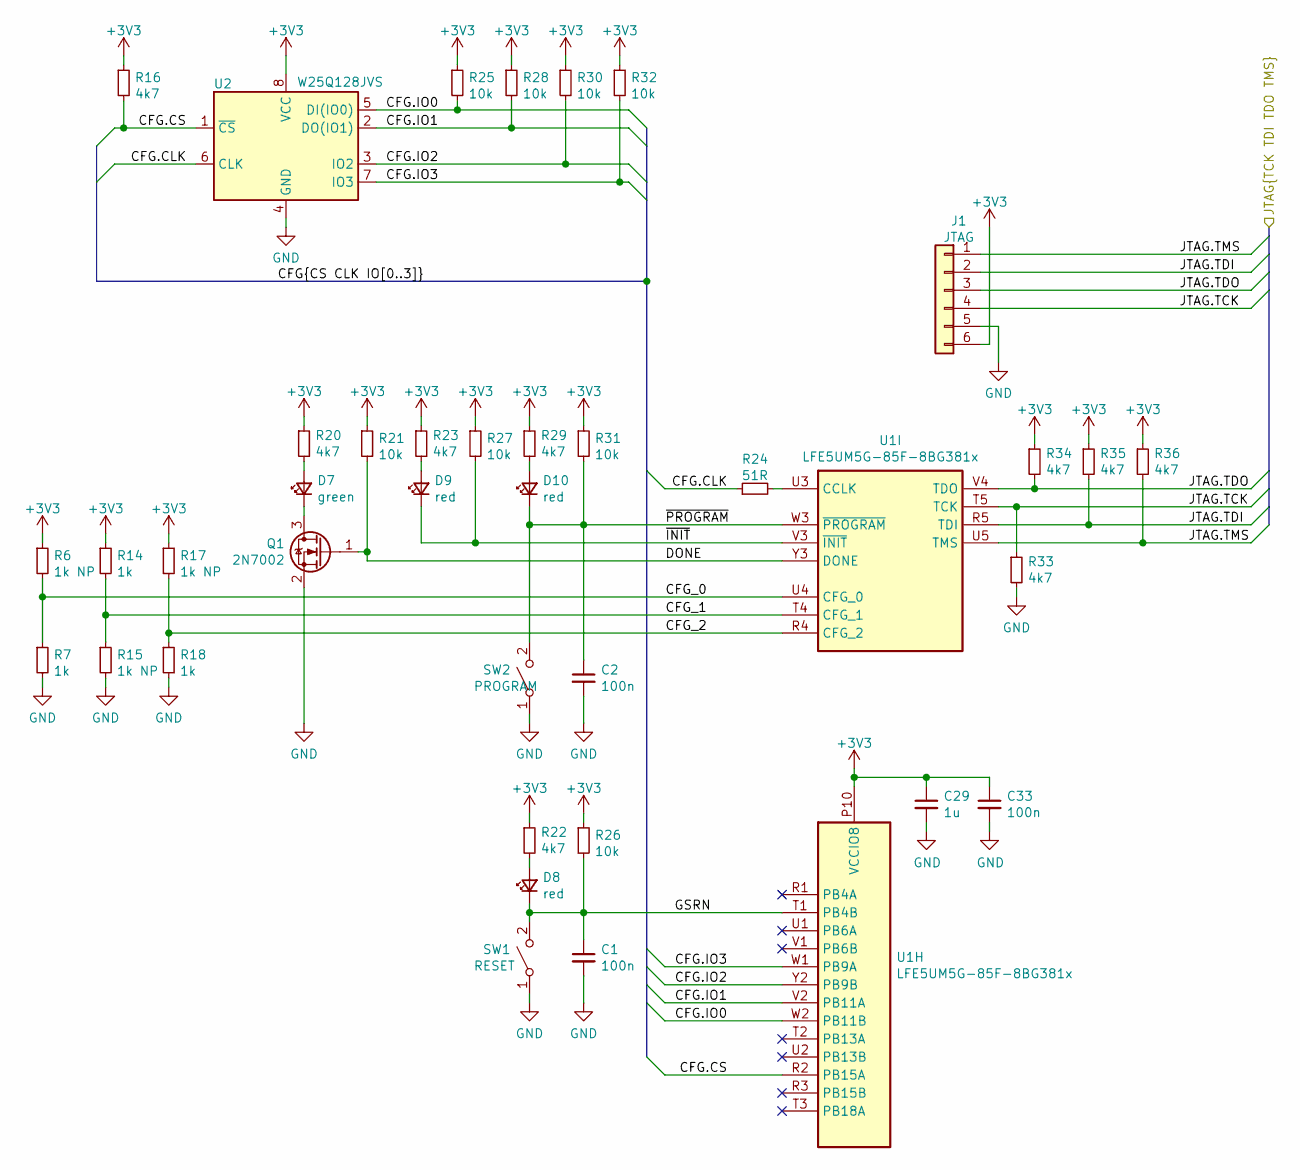
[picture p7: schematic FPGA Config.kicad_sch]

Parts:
C1, C2, C33: 100n; C_0402_1005Metric; LCSC C1525
C29: 1u; C_0402_1005Metric; LCSC C52923
D7: green; LED_0603_1608Metric; LCSC C72043
D8, D9, D10: red; LED_0603_1608Metric; LCSC C2286
J1: JTAG; PinHeader_1x06_P2.54mm_Vertical
Q1: 2N7002; SOT-23; LCSC C8545
R6, R15, R17: 1k NP; R_0402_1005Metric
R7, R14, R18: 1k; R_0402_1005Metric; LCSC C11702
R16, R20, R22, R23, R29, R33, R34, R35, R36: 4k7; R_0402_1005Metric; LCSC C25900
R21, R25, R26, R27, R28, R30, R31, R32: 10k; R_0402_1005Metric; LCSC C25744
R24: 51R; R_0402_1005Metric; LCSC C25125
SW1: RESET; SW_SPST_B3U-1000P; LCSC C231329
SW2: PROGRAM; SW_SPST_B3U-1000P; LCSC C231329
U1: LFE5UM5G-85F-8BG381x; Lattice_caBGA-381_17.0x17.0mm_Layout20x20_P0.8mm_Ball0.4mm_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
U2: W25Q128JVS; SOIC-8_5.23x5.23mm_P1.27mm; LCSC C97521

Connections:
+3V3: C29.1, C33.1, J1.6, R6.1, R14.1, R16.1, R17.1, R20.1, R21.1, R22.1, R23.1, R25.1, R26.1, R27.1, R28.1, R29.1, R30.1, R31.1, R32.1, R34.1, R35.1, R36.1, U1.P9 (VCCIO8), U1.P10 (VCCIO8), U2.8 (VCC); also elsewhere on the board
/Debug/JTAG.TCK: J1.4, R33.1, U1.T5 (TCK); also elsewhere on the board
/Debug/JTAG.TDI: J1.2, R35.2, U1.R5 (TDI); also elsewhere on the board
/Debug/JTAG.TDO: J1.3, R34.2, U1.V4 (TDO); also elsewhere on the board
/Debug/JTAG.TMS: J1.1, R36.2, U1.U5 (TMS); also elsewhere on the board
/FPGA Config/CFG.CLK: R24.1, U2.6 (CLK)
/FPGA Config/CFG.CS: R16.2, U1.R2 (PB15A), U2.1 (~CS)
/FPGA Config/CFG.IO0: R25.2, U1.W2 (PB11B), U2.5 (DI(IO0))
/FPGA Config/CFG.IO1: R28.2, U1.V2 (PB11A), U2.2 (DO(IO1))
/FPGA Config/CFG.IO2: R30.2, U1.Y2 (PB9B), U2.3 (IO2)
/FPGA Config/CFG.IO3: R32.2, U1.W1 (PB9A), U2.7 (IO3)
/FPGA Config/CFG_0: R6.2, R7.1, U1.U4 (CFG_0)
/FPGA Config/CFG_1: R14.2, R15.1, U1.T4 (CFG_1)
/FPGA Config/CFG_2: R17.2, R18.1, U1.R4 (CFG_2)
/FPGA Config/DONE: Q1.1 (G), R21.2, U1.Y3 (DONE)
/FPGA Config/GSRN: C1.1, D8.1 (K), R26.2, SW1.2 (B), U1.T1 (PB4B)
/FPGA Config/~INIT: D9.1 (K), R27.2, U1.V3 (~INIT)
/FPGA Config/~PROGRAM: C2.1, D10.1 (K), R31.2, SW2.2 (B), U1.W3 (~PROGRAM)
GND: C1.2, C2.2, C29.2, C33.2, J1.5, Q1.2 (S), R7.2, R15.2, R18.2, R33.2, SW1.1 (A), SW2.1 (A), U2.4 (GND); also elsewhere on the board
unnamed: D7.1 (K), Q1.3 (D)
unnamed: D7.2 (A), R20.2
unnamed: D8.2 (A), R22.2
unnamed: D9.2 (A), R23.2
unnamed: D10.2 (A), R29.2
unnamed: R24.2, U1.U3 (CCLK)

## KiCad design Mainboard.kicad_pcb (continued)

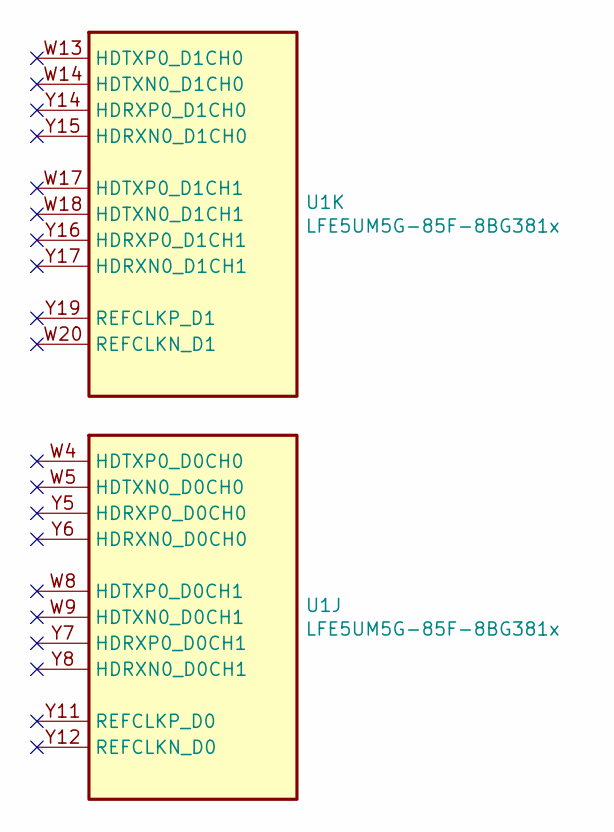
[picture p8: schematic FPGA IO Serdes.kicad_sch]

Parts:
U1: LFE5UM5G-85F-8BG381x; Lattice_caBGA-381_17.0x17.0mm_Layout20x20_P0.8mm_Ball0.4mm_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

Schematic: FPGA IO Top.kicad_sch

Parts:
C30, C32, C50: 100n; C_0402_1005Metric; LCSC C1525
C31: 1u; C_0402_1005Metric; LCSC C52923
R37, R38: 4k7; R_0402_1005Metric; LCSC C25900
U1: LFE5UM5G-85F-8BG381x; Lattice_caBGA-381_17.0x17.0mm_Layout20x20_P0.8mm_Ball0.4mm_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
U6: CAT24C256; SOIC-8_3.9x4.9mm_P1.27mm; LCSC C6482

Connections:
+3V3: C30.1, C31.1, C32.1, C50.1, R37.1, R38.1, U1.F9 (VCCIO0), U1.F10 (VCCIO0), U1.F11 (VCCIO1), U1.F12 (VCCIO1), U6.8 (VCC); also elsewhere on the board
/Audio IO/I2C1.SCL: U1.B8 (PT15B); also elsewhere on the board
/Audio IO/I2C1.SDA: U1.B9 (PT58A); also elsewhere on the board
/Audio IO/I2C2.SCL: U1.B12 (PT71A); also elsewhere on the board
/Audio IO/I2C2.SDA: U1.B13 (PT78A); also elsewhere on the board
/Audio IO/I2C3.SCL: U1.B16 (PT110B); also elsewhere on the board
/Audio IO/I2C3.SDA: U1.B17 (PT114A); also elsewhere on the board
/Audio IO/I2S1.BCLK: U1.B11 (PT65A); also elsewhere on the board
/Audio IO/I2S1.LRCLK: U1.A10 (PT63A); also elsewhere on the board
/Audio IO/I2S1.MCLK: U1.A11 (PT63B); also elsewhere on the board
/Audio IO/I2S1.SDIN: U1.B10 (PT60B); also elsewhere on the board
/Audio IO/I2S2.BCLK: U1.B15 (PT105A); also elsewhere on the board
/Audio IO/I2S2.LRCLK: U1.A14 (PT83A); also elsewhere on the board
/Audio IO/I2S2.MCLK: U1.A15 (PT103A); also elsewhere on the board
/Audio IO/I2S2.SDIN: U1.C14 (PT83B); also elsewhere on the board
/Audio IO/I2S3.BCLK: U1.B19 (PT119B); also elsewhere on the board
/Audio IO/I2S3.LRCLK: U1.A18 (PT119A); also elsewhere on the board
/Audio IO/I2S3.MCLK: U1.A19 (PT121A); also elsewhere on the board
/Audio IO/I2S3.SDIN: U1.B18 (PT116B); also elsewhere on the board
/Audio IO/I2S4.BCLK: U1.C6 (PT11A); also elsewhere on the board
/Audio IO/I2S4.LRCLK: U1.D7 (PT9B); also elsewhere on the board
/Audio IO/I2S4.MCLK: U1.D6 (PT6B); also elsewhere on the board
/Audio IO/I2S4.SDOUT: U1.C7 (PT11B); also elsewhere on the board
/Audio IO/I2S5.BCLK: U1.D8 (PT13B); also elsewhere on the board
/Audio IO/I2S5.LRCLK: U1.C9 (PT54A); also elsewhere on the board
/Audio IO/I2S5.MCLK: U1.C8 (PT15A); also elsewhere on the board
/Audio IO/I2S5.SDOUT: U1.C10 (PT58B); also elsewhere on the board
/Audio IO/IRQ1: U1.A8 (PT18B); also elsewhere on the board
/Audio IO/IRQ2: U1.A12 (PT76A); also elsewhere on the board
/Audio IO/IRQ3: U1.A16 (PT110A); also elsewhere on the board
/Audio IO/Mute1: U1.A9 (PT60A); also elsewhere on the board
/Audio IO/Mute2: U1.A13 (PT76B); also elsewhere on the board
/Audio IO/Mute3: U1.A17 (PT116A); also elsewhere on the board
/FPGA IO Top/SCL: R38.2, U1.A6 (PT4A), U6.6 (SCL)
/FPGA IO Top/SDA: R37.2, U1.B6 (PT4B), U6.5 (SDA)
GND: C30.2, C31.2, C32.2, C50.2, U6.1 (A0), U6.2 (A1), U6.3 (A2), U6.4 (GND), U6.7 (WP); also elsewhere on the board

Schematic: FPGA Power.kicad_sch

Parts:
C34, C36, C38, C40, C42, C44, C46, C48: 1u; C_0402_1005Metric; LCSC C52923
C35, C37, C39, C41, C43, C45, C47, C49: 100n; C_0402_1005Metric; LCSC C1525
U1: LFE5UM5G-85F-8BG381x; Lattice_caBGA-381_17.0x17.0mm_Layout20x20_P0.8mm_Ball0.4mm_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

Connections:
+1V2: C42.1, C43.1, C44.1, C45.1, C46.1, C47.1, C48.1, C49.1, U1.H8 (VCC), U1.H9 (VCC), U1.H10 (VCC), U1.H11 (VCC), U1.H12 (VCC), U1.H13 (VCC), U1.J8 (VCC), U1.J13 (VCC), U1.K8 (VCC), U1.K13 (VCC), U1.L8 (VCC), U1.L13 (VCC), U1.M8 (VCC), U1.M13 (VCC), U1.N8 (VCC), U1.N9 (VCC), U1.N10 (VCC), U1.N11 (VCC), U1.N12 (VCC), U1.N13 (VCC), U1.T6 (VCCA0), U1.T7 (VCCHTX0_D0CH0), U1.T10 (VCCHTX1_D0CH1), U1.T11 (VCCHTX0_D1CH0), U1.T14 (VCCHTX1_D1CH1), U1.T15 (VCCA1), U1.U6 (VCCA0), U1.U15 (VCCA1); also elsewhere on the board
+2V5: C34.1, C35.1, C36.1, C37.1, C38.1, C39.1, C40.1, C41.1, U1.F6 (VCCAUX), U1.F15 (VCCAUX), U1.P6 (VCCAUX), U1.P15 (VCCAUX); also elsewhere on the board
GND: C34.2, C35.2, C36.2, C37.2, C38.2, C39.2, C40.2, C41.2, C42.2, C43.2, C44.2, C45.2, C46.2, C47.2, C48.2, C49.2, U1.B7 (GND), U1.B14 (GND), U1.C19 (GND), U1.D4 (GND), U1.F7 (GND), U1.F8 (GND), U1.F13 (GND), U1.F14 (GND), U1.G4 (GND), U1.G6 (GND), U1.G7 (GND), U1.G8 (GND), U1.G9 (GND), U1.G10 (GND), U1.G11 (GND), U1.G12 (GND), U1.G13 (GND), U1.G14 (GND), U1.G15 (GND), U1.G17 (GND), U1.H19 (GND), U1.J2 (GND), U1.J7 (GND), U1.J9 (GND), U1.J10 (GND), U1.J11 (GND), U1.J12 (GND), U1.J14 (GND), U1.K6 (GND), U1.K7 (GND), U1.K9 (GND), U1.K10 (GND), U1.K11 (GND), U1.K12 (GND), U1.K14 (GND), U1.K15 (GND), U1.L9 (GND), U1.L10 (GND), U1.L11 (GND), U1.L12 (GND), U1.M2 (GND), U1.M7 (GND), U1.M9 (GND), U1.M10 (GND), U1.M11 (GND), U1.M12 (GND), U1.M14 (GND), U1.M16 (GND), U1.N6 (GND), U1.N7 (GND), U1.N14 (GND), U1.N15 (GND), U1.P7 (GND), U1.P8 (GND), U1.P11 (GND), U1.P12 (GND), U1.P13 (GND), U1.P14 (GND), U1.R19 (GND), U1.U7 (GND), U1.U8 (GND), U1.U9 (GND), U1.U10 (GND), U1.U11 (GND), U1.U12 (GND), U1.U13 (GND), U1.U14 (GND), U1.V5 (GND), U1.V6 (GND), U1.V7 (GND), U1.V8 (GND), U1.V9 (GND), U1.V12 (GND), U1.V13 (GND), U1.V14 (GND), U1.V15 (GND), U1.V16 (GND), U1.V19 (GND), U1.V20 (GND), U1.W6 (GND), U1.W7 (GND), U1.W12 (GND), U1.W15 (GND), U1.W16 (GND), U1.W19 (GND); also elsewhere on the board

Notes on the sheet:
V_CC (Core): 1.2 V V_CCAUX (Aux): 2.5 V V_CCA (SERDES Analog): 1.2 V (connected to V_CC if unused) V_CCAUXA (SERDES Aux): 2.5 V (open if unused) V_CCHRX (SERDES Input Buffer): 1.2 V (open if unused) V_CCHTX (SERDES Output Buffer): 1.2 V (open/V_CCA if unused)

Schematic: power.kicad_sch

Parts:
C4, C5, C6: 4u7; C_0603_1608Metric; LCSC C19666
C7, C8, C9: 6p8; C_0402_1005Metric; LCSC C1576
C10, C11, C16, C17: 10u; C_0603_1608Metric; LCSC C19702
C12, C18: 22u; C_0603_1608Metric; LCSC C59461
C13, C14, C15: 1u; C_0603_1608Metric; LCSC C15849
D1, D2: green; LED_0603_1608Metric; LCSC C72043
D12: red; LED_0603_1608Metric; LCSC C2286
F1: 2A; Fuse_0603_1608Metric_Pad1.05x0.95mm_HandSolder; LCSC C187605
J2: Power; JST_VH_B4P-VH_1x04_P3.96mm_Vertical
L3, L4, L5: 2u2; L_0805_2012Metric; LCSC C216156
R1, R9: 15k; R_0402_1005Metric; LCSC C25756
R2, R43: 4k7; R_0402_1005Metric; LCSC C25900
R8: 68k; R_0402_1005Metric; LCSC C36871
R10: 150k; R_0402_1005Metric; LCSC C25755
R11: 47k; R_0402_1005Metric; LCSC C25792
R12, R13: 100k; R_0402_1005Metric; LCSC C25741
TP4: 3V3; TestPoint_Pad_D1.5mm
TP5: 2V5; TestPoint_Pad_D1.5mm
TP6: 1V2; TestPoint_Pad_D1.5mm
U3, U4, U5: TLV62569DBV; SOT-23-5; LCSC C141836

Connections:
+1V2: C9.1, C12.1, C15.1, C18.1, L5.2, R12.1, TP6.1; also elsewhere on the board
+2V5: C8.1, C11.1, C14.1, C17.1, L4.2, R10.1, TP5.1; also elsewhere on the board
+3V3: C7.1, C10.1, C13.1, C16.1, L3.2, R2.1, R8.1, TP4.1; also elsewhere on the board
+5V: C4.2, C5.2, C6.2, F1.2, R1.1, R43.1, U3.1 (EN), U3.4 (VIN), U4.1 (EN), U4.4 (VIN), U5.1 (EN), U5.4 (VIN)
/Power/PWR_IN: D12.2 (A), F1.1, J2.1, J2.2
GND: C4.1, C5.1, C6.1, C10.2, C11.2, C12.2, C13.2, C14.2, C15.2, C16.2, C17.2, C18.2, D1.1 (K), D2.1 (K), J2.3, J2.4, R9.2, R11.2, R13.2, U3.2 (GND), U4.2 (GND), U5.2 (GND); also elsewhere on the board
unnamed: C7.2, R8.2, R9.1, U3.5 (FB)
unnamed: C8.2, R10.2, R11.1, U4.5 (FB)
unnamed: C9.2, R12.2, R13.1, U5.5 (FB)
unnamed: D1.2 (A), R1.2
unnamed: D2.2 (A), R2.2
unnamed: D12.1 (K), R43.2
unnamed: L3.1, U3.3 (SW)
unnamed: L4.1, U4.3 (SW)
unnamed: L5.1, U5.3 (SW)

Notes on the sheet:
3.3V
2.5V
1.2V

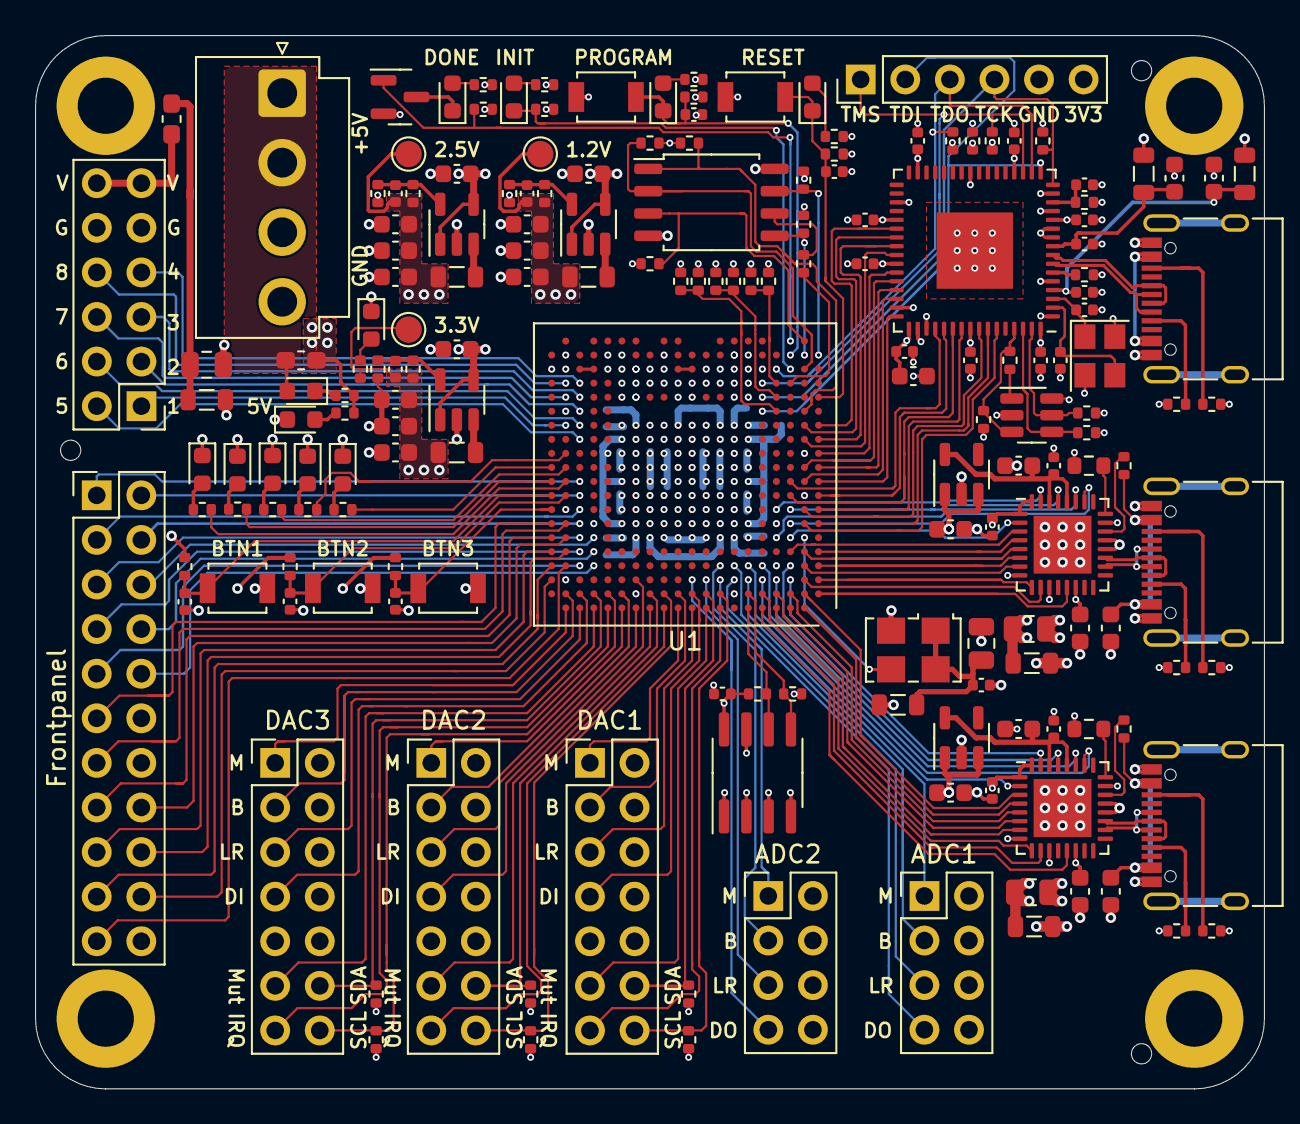
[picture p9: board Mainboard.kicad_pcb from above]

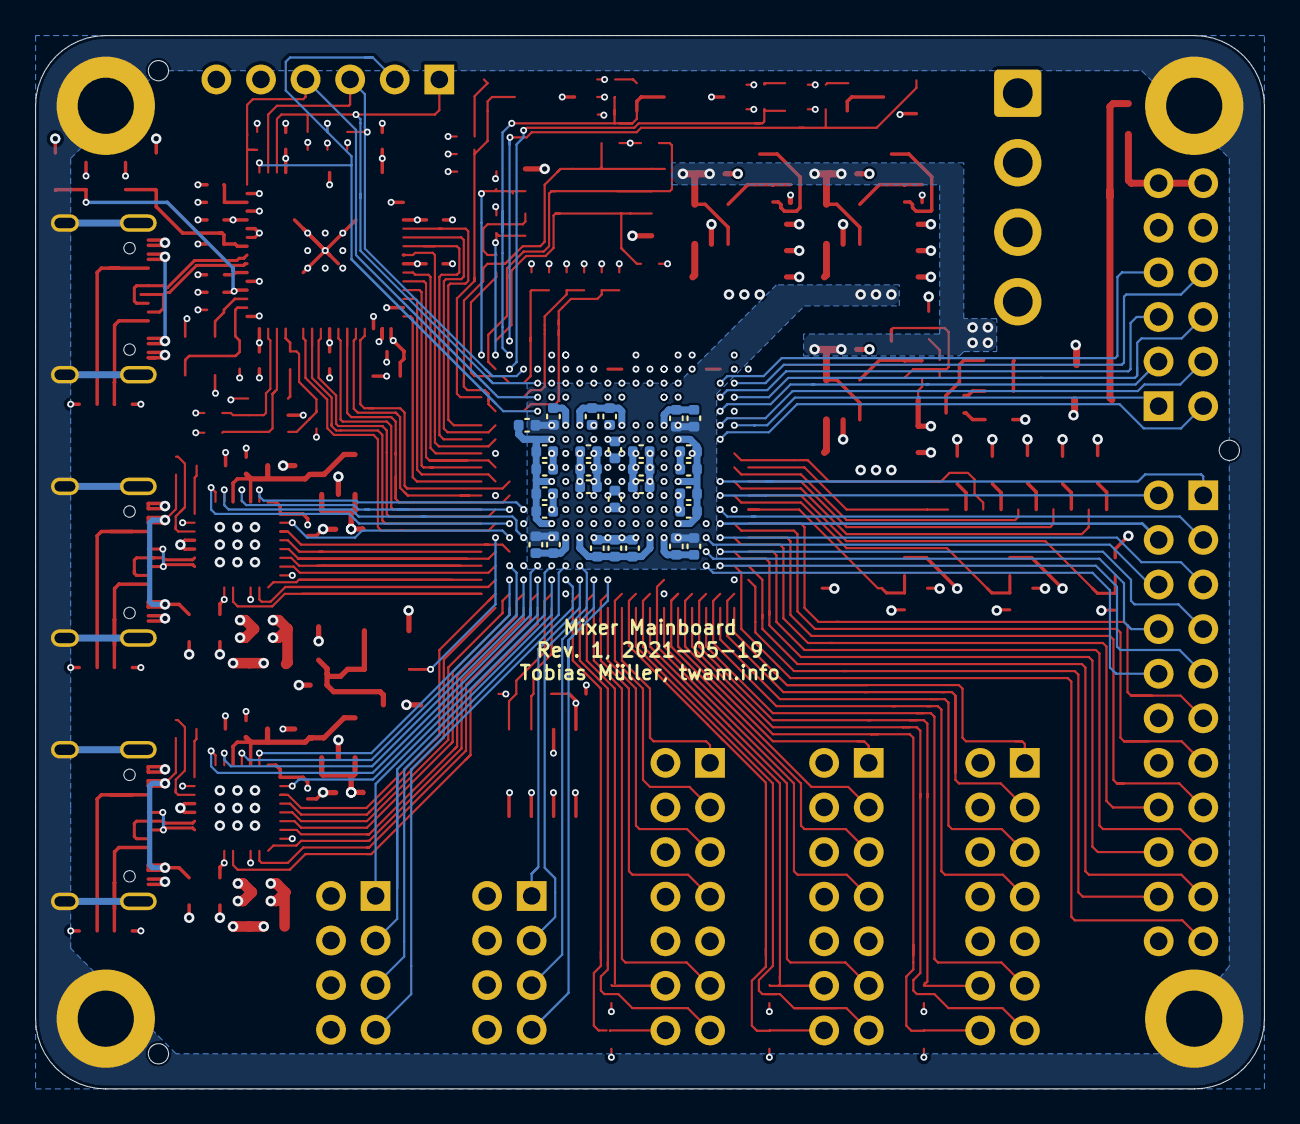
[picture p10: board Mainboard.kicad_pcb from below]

Board: 4 copper layers, 70.0 x 60.0 mm, 213 parts (29 on the bottom side), 193 nets.

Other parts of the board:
C101: 10u; C_0805_2012Metric
C102: 1u; C_0603_1608Metric
C103: 10u; C_0603_1608Metric
C104, C106: 2u2; C_0603_1608Metric
C105, C107: 100n; C_0402_1005Metric
J101: USB1; USB_C_Receptacle_XKB_TYPE-C-31-M-12
L101: 600R/100M; L_0805_2012Metric
R101, R102: 5k1; R_0402_1005Metric
R104: 10k; R_0402_1005Metric
R105: 8k06 1%; R_0603_1608Metric
U101: USB3320; QFN-32-1EP_5x5mm_P0.5mm_EP3.3x3.3mm
U102: TPS76318; SOT-23-5

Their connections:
+3V3: L101.1; also elsewhere on the board
/FPGA IO Left/ULPI1.CLK: U101.26 (REFCLK); also elsewhere on the board
/FPGA IO Left/ULPI1.DIR: U101.31 (DIR); also elsewhere on the board
/FPGA IO Left/ULPI1.D_{0}: U101.3 (DATA0); also elsewhere on the board
/FPGA IO Left/ULPI1.D_{1}: U101.4 (DATA1); also elsewhere on the board
/FPGA IO Left/ULPI1.D_{2}: U101.5 (DATA2); also elsewhere on the board
/FPGA IO Left/ULPI1.D_{3}: U101.6 (DATA3); also elsewhere on the board
/FPGA IO Left/ULPI1.D_{4}: U101.7 (DATA4); also elsewhere on the board
/FPGA IO Left/ULPI1.D_{5}: U101.9 (DATA5); also elsewhere on the board
/FPGA IO Left/ULPI1.D_{6}: U101.10 (DATA6); also elsewhere on the board
/FPGA IO Left/ULPI1.D_{7}: U101.13 (DATA7); also elsewhere on the board
/FPGA IO Left/ULPI1.NXT: U101.2 (NXT); also elsewhere on the board
/FPGA IO Left/ULPI1.RST: U101.27 (RESETB); also elsewhere on the board
/FPGA IO Left/ULPI1.STP: U101.29 (STP); also elsewhere on the board
/USB1/1V8_USB: C103.1, C107.1, U101.28 (VDD18), U101.30 (VDD18), U102.5 (VOUT)
/USB1/3V3_USB: C101.1, C102.1, C105.1, C106.1, L101.2, U101.1 (CLKOUT), U101.8 (REFSEL0), U101.11 (REFSEL1), U101.14 (REFSEL2), U101.20 (VDD33), U101.21 (VBAT), U101.23 (ID), U101.32 (VDDIO), U102.1 (VIN), U102.3 (EN)
/USB1/CC1: J101.A5 (CC1), R101.2
/USB1/CC2: J101.B5 (CC2), R102.2
/USB1/D+: J101.A6 (D+), J101.B6 (D+), U101.18 (DP)
/USB1/D-: J101.A7 (D-), J101.B7 (D-), U101.19 (DM)
/USB1/VBUS: C104.1, J101.A4 (VBUS), J101.A9 (VBUS), J101.B4 (VBUS), J101.B9 (VBUS), R104.1
Earth: J101.S1 (SHIELD); also elsewhere on the board
GND: C101.2, C102.2, C103.2, C104.2, C105.2, C106.2, C107.2, J101.A1 (GND), J101.A12 (GND), J101.B1 (GND), J101.B12 (GND), R101.1, R102.1, R105.2, U101.33 (GND), U102.2 (GND); also elsewhere on the board
unnamed: R104.2, U101.22 (VBUS)
unnamed: R105.1, U101.24 (RBIAS)

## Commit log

2021-06-05 Initial commit. Rev 1
    [Audio IO.kicad_sch, Debug.kicad_sch, Debug.sch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]
2022-01-07 Update to KiCad 6
    [Audio IO.kicad_sch, Debug.kicad_sch, Debug.sch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]

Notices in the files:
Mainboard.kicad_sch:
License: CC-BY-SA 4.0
